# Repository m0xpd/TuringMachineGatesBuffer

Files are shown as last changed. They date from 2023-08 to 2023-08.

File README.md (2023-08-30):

# Turing Machine Gates Buffer
This repository contains design details for an add-on circuit, which buffers signals from the GATES Expander port of [Music Thing Modular](https://www.musicthing.co.uk/)'s [Turing Machine](https://www.musicthing.co.uk/Turing-Machine/) random looping sequencer.

<p width=100%, align="center">

</p>

This buffer circuit was developed in response to my own requirement to obtain reliable output voltages from the Turing Machine's GATES expander port, 
particularly when using the [Voltages expander](https://www.musicthing.co.uk/Turing-Voltages-Expander/) under my ['Tuning Strategy'](https://github.com/m0xpd/TuningStrategyForVoltages), 
where small voltage errors immediately cause noticeable tuning problems.

The buffer requires no modifications to the Turing Machine - it plugs onto the GATES and Power headers, which it replaces. There is an option to add a spacer 
and an M3 screw down to one of the tapped spacers on the Turing Machine for mechanical stability, which is strongly recommended.

# Background

I had noticed a tendency for the voltages produced at the GATES output of the Turing Machine to droop when a large number of bits were activated in 
the 'gate' sequence. This problem was exacerbated when the [PULSES expander](https://www.musicthing.co.uk/Turing-Pulse-Expander/) was used. 
The Turing Machine's power line '+12V_BACK' was observed to droop by over 1V under such loading conditions (*when no such change was seen on the system 
power supply*), making the fall in the GATEx output voltages less surprising (although the 78L09 regulated supply to the CD4050's *should* have prevented 
this - see below).

Designing a buffer for the GATE outputs under these conditions required that the additional circuit did not rely on the either the board's 12V supply or the 
magnitude of the GATEx signals. 

Although a number of design options were possible, I chose to use CD4066 "Analog Switches" (which are inexpensive and familiar to the synth DIY community) 
controlled by the GATE signals, to switch a steady voltage to the GATES expander port.

In the Turing Machine design, the GATE signals are at 9V (the supply Voltage provided to the 4050 "Buffers"). I decided to drop this to 5V i) to give more clear 
air between the failing supply and the voltage level and ii) because it is consistent with the needs of my [tuning strategy](https://github.com/m0xpd/TuningStrategyForVoltages) (where I already set the SCALE control on VOLTAGES quite low). I couln't go much lower, because I still wanted the LEDs on VOLTAGES to light up with no modifications.

Here's my schematic (click for a full-size version):

<p width=100%, align="center">

</p>  

There are .sch and .brd files (developed in EAGLE) for the printed circuit board in the [PCB folder](https://github.com/m0xpd/TuringMachineGatesBuffer/tree/main/PCB), along with a BoM (in EAGLE's usual format).

# Specifications

The buffer adds an additional 14 mm of depth to the Turing Machine, making the Turing Machine & Buffer extend 50 mm behind the front panel when a standard power 
header is inserted into the buffer's power receptacle (55mm if the power cable's IDC header has a strain relief fitted).

<p width=100%, align="center">

</p> 

The buffer draws 2mA of current from the +12V rail and nothing from the 5V or -12V rails. 

# License

This design is published under a [Creative Commons BY-SA 4.0](https://github.com/m0xpd/TuringMachineGatesBuffer/blob/main/LICENSE.txt) License.

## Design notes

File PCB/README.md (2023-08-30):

# PCB

Design files for the gates buffer printed circuit board in EAGLE format are in this folder.

There is a .sch and a .brd file and a Bill of Materials.

The prototype was manufactured by [JCLPCB](https://jlcpcb.com/) (usual disclaimer), who did a great job. The populated  board is seen below from both sides:

<p width=100%, align="center">

</p>

The BoM lists JP1, JP2 and JP3 as PIN HEADERS. It will be seen in the image above that JP1 and JP3 are populated by female headers (sockets) on the underside 
of the board.

JP1 is a 2 * 8, 0.1 inch pitch socket (which mates with the Turing Machine's GATES expander header) and JP3 is a 2 * 5, 0.1 inch pitch socket, which mates 
with the Turing Machine's power connecter.

[I cut these from 2 * 40 socket strips, rather than keep smaller size sockets - it is cheaper and easier in 'stock control'.]

JP2 is a male 2 * 8 header, mounted on the top (component) side of the board, which becomes the new GATES expander.

The buffer specifies a shrouded male header for the power connection, which avoids the possibility of incorrect power cable orientation. You can fit a plain 2 * 5 
male header here if you prefer.

It is seen that the board edge is profiled to allow access to the PULSES expander port.

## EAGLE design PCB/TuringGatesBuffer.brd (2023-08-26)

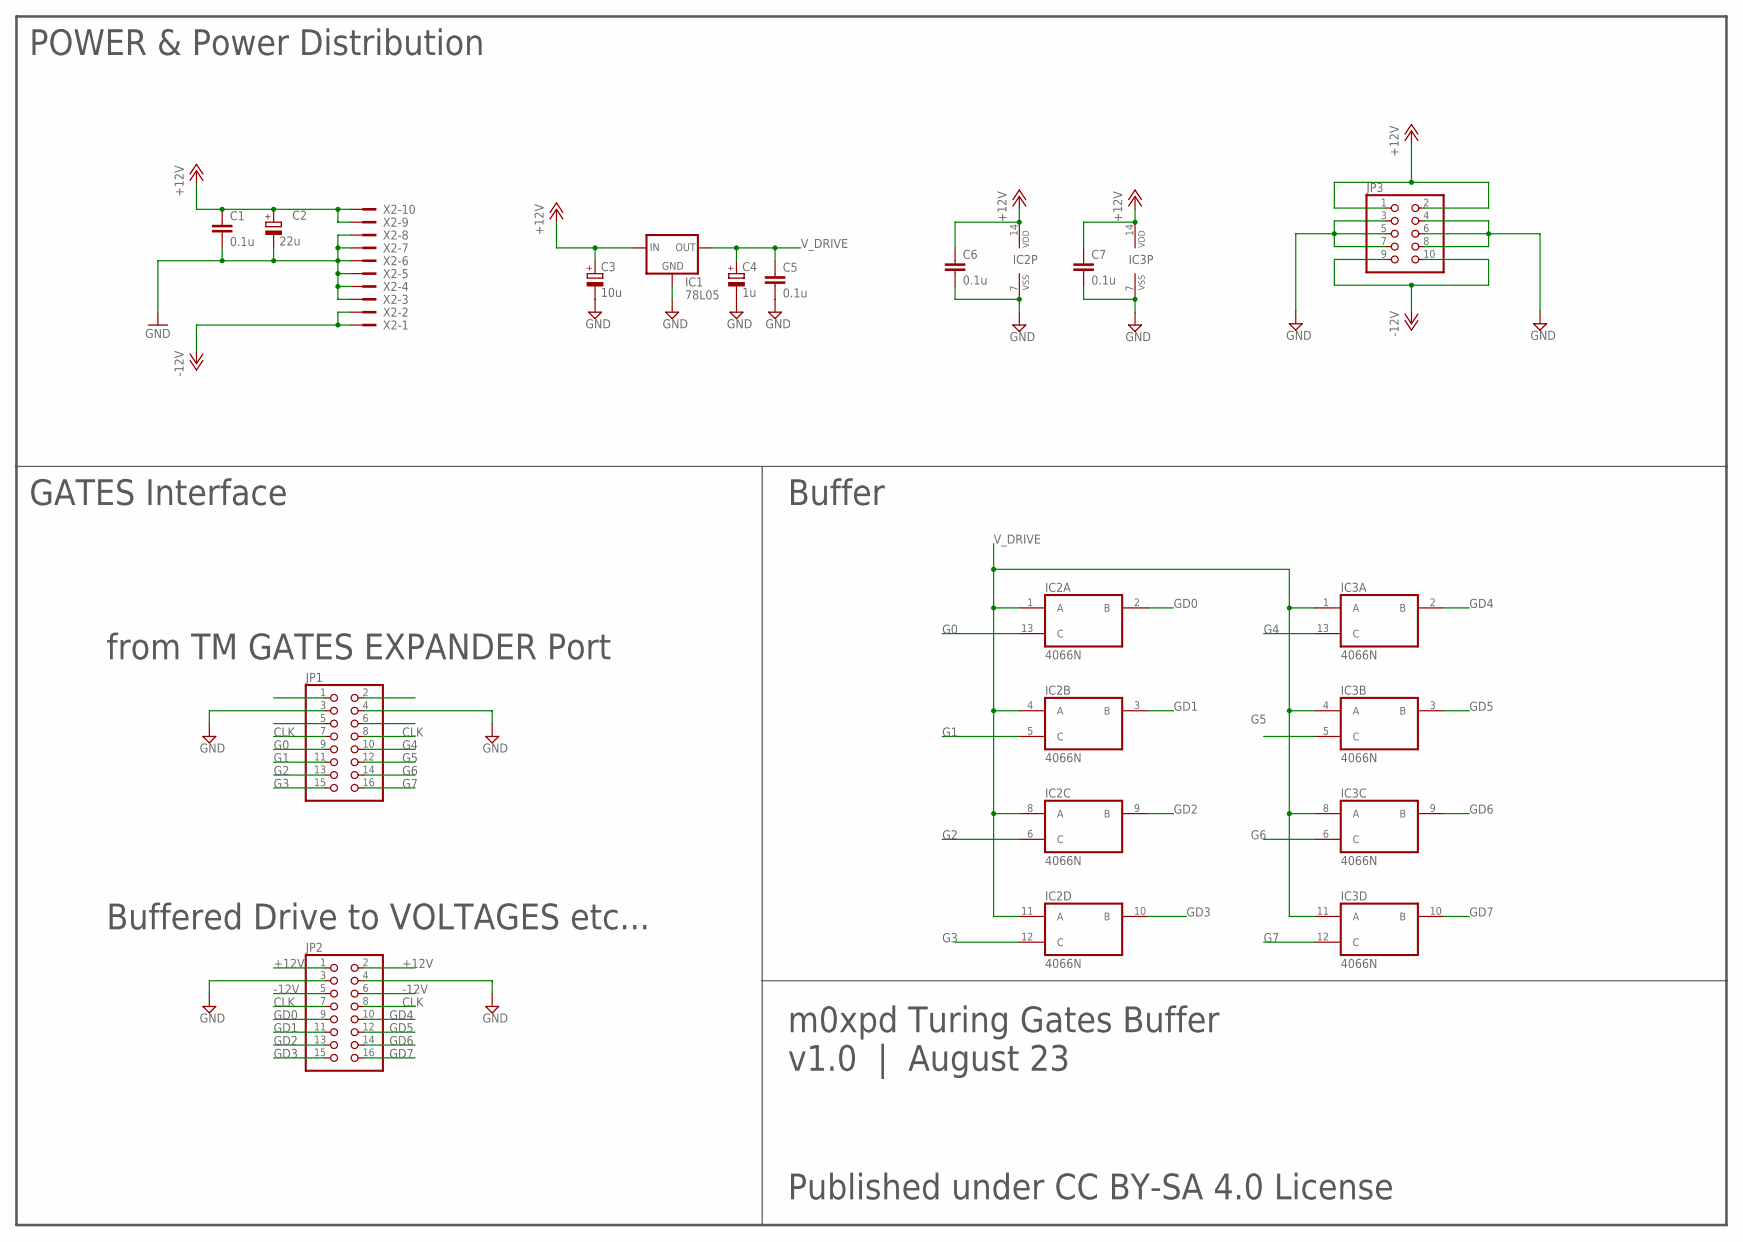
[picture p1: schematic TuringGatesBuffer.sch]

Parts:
C1, C5, C6, C7: 0.1u; C050-025X075
C2: 22u; E2,5-5
C3: 10u; E2,5-5
C4: 1u; E2,5-5
IC1: 78L05; 78LXX
IC2, IC3: 4066N; DIL14
JP1, JP2: PINHD-2X8; 2X08
JP3: PINHD-2X5; 2X05
X2: 2510-; PAK100/2500-10

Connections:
+12V: C1.1, C2.+, C3.+, C6.1, C7.1, IC1.IN, IC2.14 (VDD), IC3.14 (VDD), JP2.1, JP2.2, JP3.1, JP3.2, X2.9, X2.10
-12V: JP2.5, JP2.6, JP3.9, JP3.10, X2.1, X2.2
CLK: JP1.7, JP1.8, JP2.7, JP2.8
G0: IC2.13 (C), JP1.9
G1: IC2.5 (C), JP1.11
G2: IC2.6 (C), JP1.13
G3: IC2.12 (C), JP1.15
G4: IC3.13 (C), JP1.10
G5: IC3.5 (C), JP1.12
G6: IC3.6 (C), JP1.14
G7: IC3.12 (C), JP1.16
GD0: IC2.2 (B), JP2.9
GD1: IC2.3 (B), JP2.11
GD2: IC2.9 (B), JP2.13
GD3: IC2.10 (B), JP2.15
GD4: IC3.2 (B), JP2.10
GD5: IC3.3 (B), JP2.12
GD6: IC3.9 (B), JP2.14
GD7: IC3.10 (B), JP2.16
GND: C1.2, C2.-, C3.-, C4.-, C5.2, C6.2, C7.2, IC1.GND, IC2.7 (VSS), IC3.7 (VSS), JP1.3, JP1.4, JP2.3, JP2.4, JP3.3, JP3.4, JP3.5, JP3.6, JP3.7, JP3.8, X2.3, X2.4, X2.5, X2.6, X2.7, X2.8
V_DRIVE: C4.+, C5.1, IC1.OUT, IC2.1 (A), IC2.4 (A), IC2.8 (A), IC2.11 (A), IC3.1 (A), IC3.4 (A), IC3.8 (A), IC3.11 (A)

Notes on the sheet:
m0xpd Turing Gates Buffer
v1.0 | August 23
Published under CC BY-SA 4.0 License
Buffer
GATES Interface
POWER & Power Distribution
from TM GATES EXPANDER Port
Buffered Drive to VOLTAGES etc...

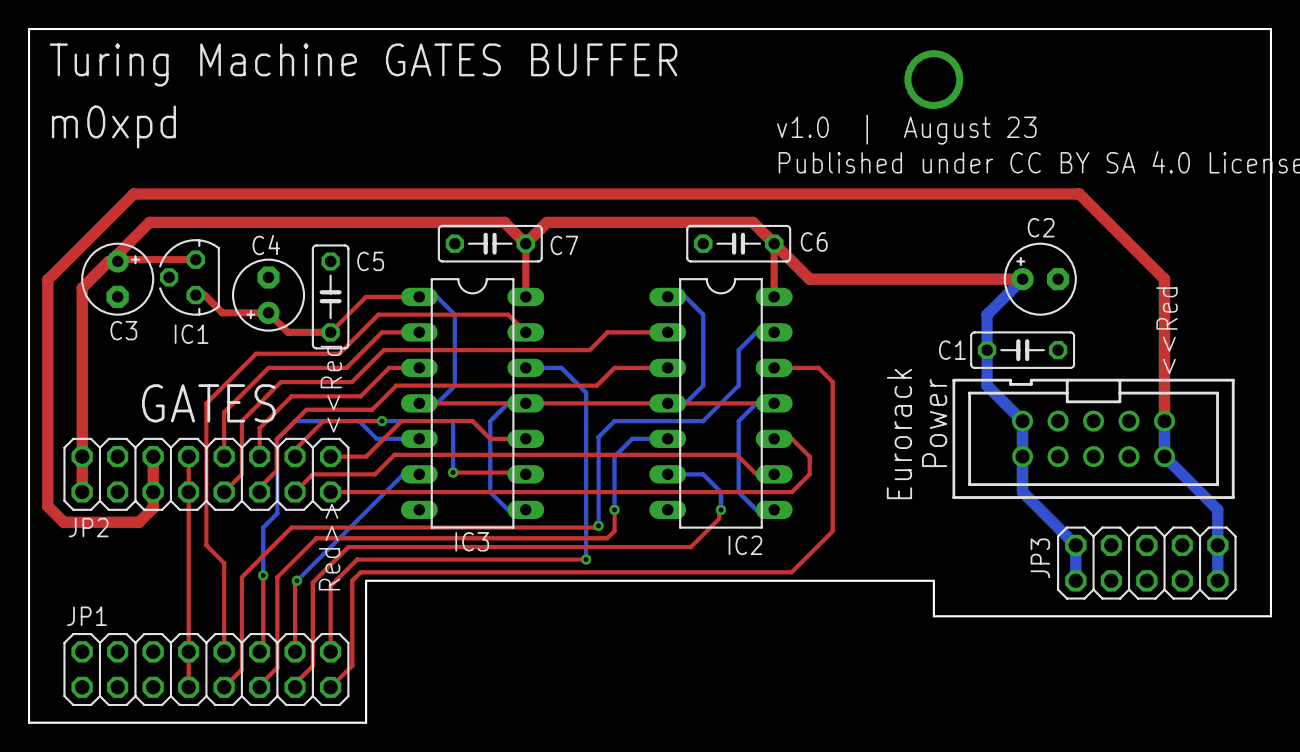
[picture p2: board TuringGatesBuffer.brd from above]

Board: 2 copper layers, 88.9 x 49.7 mm, 14 parts (0 on the bottom side), 21 nets.
